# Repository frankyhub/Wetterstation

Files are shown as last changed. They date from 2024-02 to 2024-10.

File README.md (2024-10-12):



<div align="center">

|[:skull:ISSUE](https://github.com/frankyhub/Wetterstation/issues?q=is%3Aissue)|[:speech_balloon: Forum /Discussion](https://github.com/frankyhub/Wetterstation/discussions)|[:grey_question:WiKi](https://github.com/frankyhub/Wetterstation/wiki)||
|--|--|--|--|
| | | | |
||<a href="https://github.com/frankyhub/Wetterstation/issues">|<a href="https://github.com/frankyhub/Wetterstation/discussions">|<a href="https://github.com/frankyhub/Wetterstation/releases">|
|| <a href="https://github.com/frankyhub/Wetterstation/pulse" alt="Activity">| <a href="https://github.com/frankyhub/Wetterstation/graphs/traffic">  |<a href="https://github.com/frankyhub?tab=stars"> |
</div>

# Wetterstation
Wetterdaten, Raumklima, Datum und Uhrzeit

## Story:
Diese Anleitung beschreibt den Aufbau einer Wetterstation in einem Holzgehäuse mit einem ESP32. Beim ESP32 ist ein DHT11-Sensor und am I²C-Bus ein OLED 1,3"-Display angeschlossen. Die Wetterstation beinhaltet einen WiFi-Manager für die Einstellung der WLAN-Zugangsdaten (SSID und Passwort). Nach den ersten Start der Wetterstation, muss in den WLAN-Einstellungen des Handy oder Tablet das Netzwerk "Wetterstation" ausgewählt und über einen Browser die IP-Adresse 192.168.4.1 aufgerufen werden. Danach startet die "Wetterstation WLAN-Einstellung" und die Zugangsdaten für das WLAN können eingetragen werden. Sind die Zugangsdaten korrekt, startet die Wetterstation.
Die Wetterstation zeigt beim Start für 5 Sekunden einen Smiley. In dieser Zeit werden die aktuelle Uhrzeit, das Datum und die aktuellen Wetterdaten aus der Region Tegernsee von de.pool.ntp.org und von openweathermap.org geladen.
Sind die Daten geladen, verschwindet der Smiley und es werden in regelmäßigen Abständen drei Seiten mit Datum und Uhrzeit, danach das Raumklima mit Temperatur und Luftfeuchte, zuletzt die Wetterdaten Außen-Temperatur, Windgeschwindigkeit und Luftdruck angezeigt.

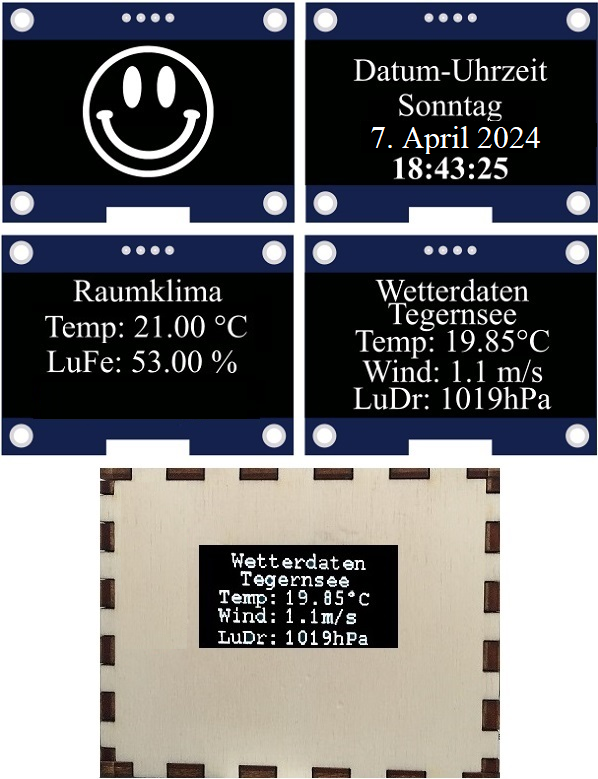
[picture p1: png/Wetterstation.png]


## Hardware:
Das benötigen wir für die Wetterstation:

| Anzahl | Bezeichnung | 
| --- | --- |
| 1 | ESP32 |
| 1 | ESP32-Shield | 
| 1 | ESP32 Stiftleiste | 
| 1 | DHT11-Sensor | 
| 1 | 10k Widerstand | 
| 1 | OLED Display 1,3" I²C | 
| 1 | OLED Display Anschluss 4 pol. |
| 1 | 8V Netzteil | 
| 1 | Sperrholzplatte 4mm x 600x300 | 
| 1 | 3D-Druck Teile für den ESP32, das OLED-Display und den DHT11 | 
| 1 | Schaltdraht | 
| 1 | Sekundenkleber | 
| 1 | Holzkleber |
| -------- | -------- | 

## Der Aufbau erfolgt in 5 Schritten:

1. Schritt Verdrahten

+ Wir löten auf das ESP32-Shield die Stiftleisten
+ Am ESP32-Shield wird ein 10kΩ Pullupwiderstand gegen +5V angelötet
+ Wir schließen mit Schaltdraht den DHT11-Sensor am ESP32-Shield GPIO27 an
+ Wir verdrahten den DHT11 mit +5V und GND
+ Wir verbinden mit Schaltdraht den I²C-Bus mit dem Display
+ Dazu werden die Lötpunkte SLA, SLC, 3.3V und GND mit dem Display verbunden
+ Ist der ESP32 auf dem Shield, der Sensor und das Display angelötet, erfolgt der erste Test
+ Wir laden einen I²C-Scanner in den ESP32 und kontrollieren ob der ESP32 die Busteilnehmer erkennt
+ Wird das Display erkannt, laden wir das Haupt-Programm in den ESP32

Stiftleisten einlöten:
  
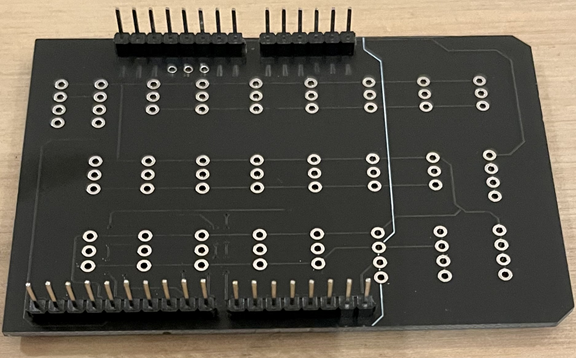
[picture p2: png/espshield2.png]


DHT11 anlöten:

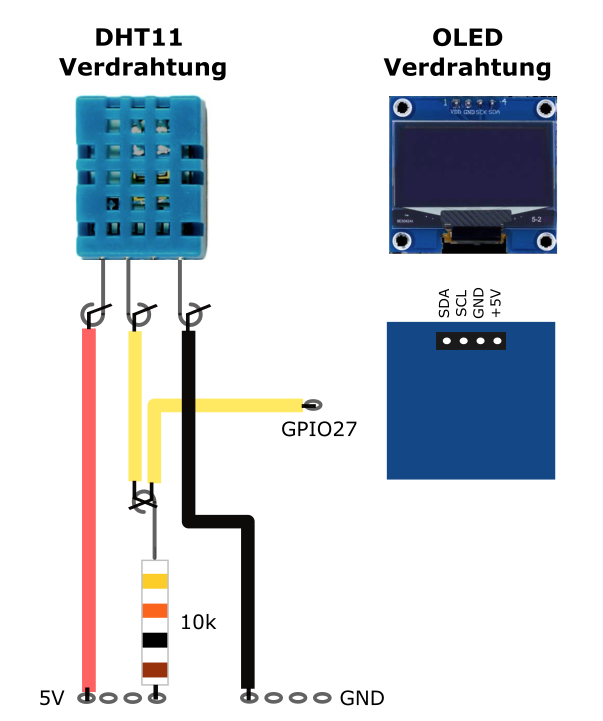
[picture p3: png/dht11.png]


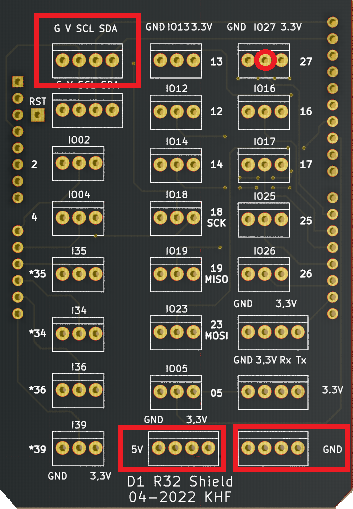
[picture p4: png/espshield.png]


Bild

---

2. Schritt 3D-Druckteile zeichnen und drucken

+ 3D-Druckteile zeichnen und drucken
+ 4 x ESP32-Pins d=5mm h=7mm
+ 4 x OLED-Display Pins 10x4x1,6mm
+ 1 x DHT11-Halterung 24x8x21 mit DHT11 Aussparung

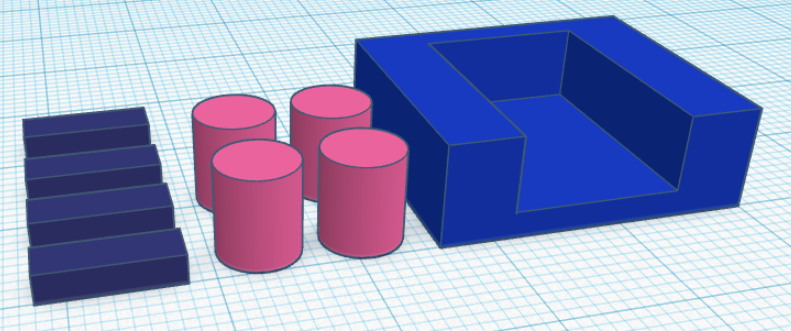
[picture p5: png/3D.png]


---

3. Schritt Gehäuse lasern

+ Wir erstellen mit [BOXES.PY](https://festi.info/boxes.py/) eine Lasercutter Vorlage
+ Wähle die ClosedBox - Fully closed box mit den Maßen x=110, y=90, h=90 und thickness=4
+ Zusätzlich werden runde Öffnungen für den DHT11-Sensor in der Frontseinte,
+ eine Aussparung für das OLED-Display und
+ zwei Aussparungen für den Spannungs- und Programmieranschluss des ESP32 in der Seitenwand eingefügt

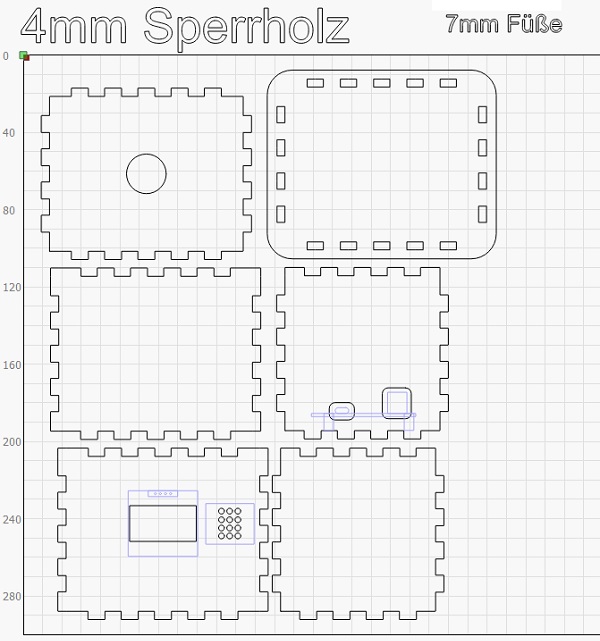
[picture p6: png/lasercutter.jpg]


---

4. Schritt Montage

+ Mit Sekundenkleber die 3D-Druck Bauteilfüße auf den ESP32 kleben
+ Die 3D-Druck Leisten auf das OLED-Display kleben
+ Die DHT11-Halterung an die Front-Innenseite kleben
+ VORSICHTIG das Display an die Front-Innenseite kleben
+ Den ESP32 zu den Aussparungen der Seitenwand justieren und auf die Grundplatte kleben
+ Vor dem finalen verkleben des Gehäuses erfolgt ein Funktionstest
+ War der Funktionstest erfolgreich, kann das Gehäuse vollständig verklebt werden

Bild  

Bild  

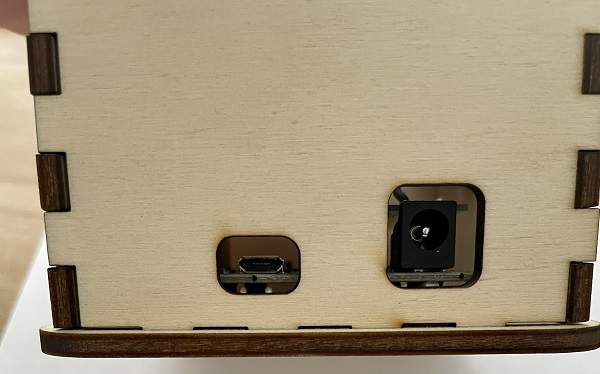
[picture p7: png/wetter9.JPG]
  

Erster Funktionstest am Seriellen Monitor:

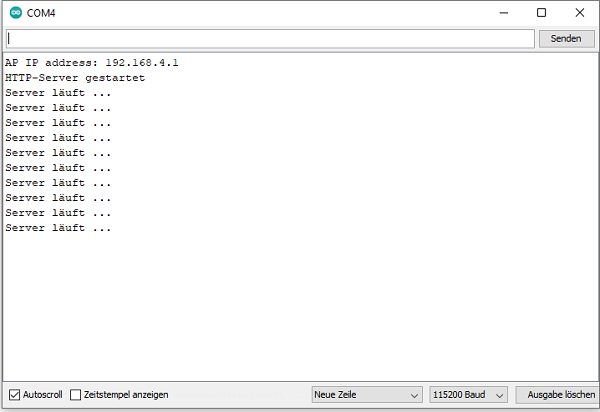
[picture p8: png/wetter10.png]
  

---

5. Schritt Inbetriebnahme

+ Im Handy oder Tablet die WLAN-Einstellungen öffnen
+ Das Netzwerk "Wetterstation" aufrufen
+ Im Browser die IP-Adresse 192.168.4.1 aufrufen
+ Die Seite "Wetterstation WLAN Einstellung" öffnet sich
+ Die WLAN-Zugangsdaten SSID und Passwort eingeben und speichern
+ Der Zeitserver ist voreingestellt und muss nicht verändert werden
+ Ist die WLAN-Verbindung korrekt, startet die Wetterstation mit einem Smiley am Display
+ Danach werden abwechselnd das aktuelle Datum mit Uhrzeit, danach das Raumklima mit Temperatur und Luftfeuchte und die aktuellen Wetterdaten aus der Region Tegernsee angezeigt
+ Die angezeigten Daten wechseln in regelmäßigen Abständen

Aufruf "Wetterstation" in den WLAN-Einstellungen

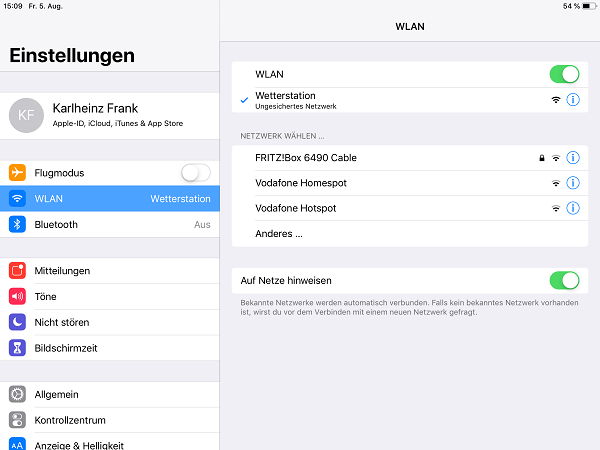
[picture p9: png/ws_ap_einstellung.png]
  

Im Browser die IP-Adresse 192.168.4.1 öffnen, die WLAN Zugangsdaten eingeben und speichern

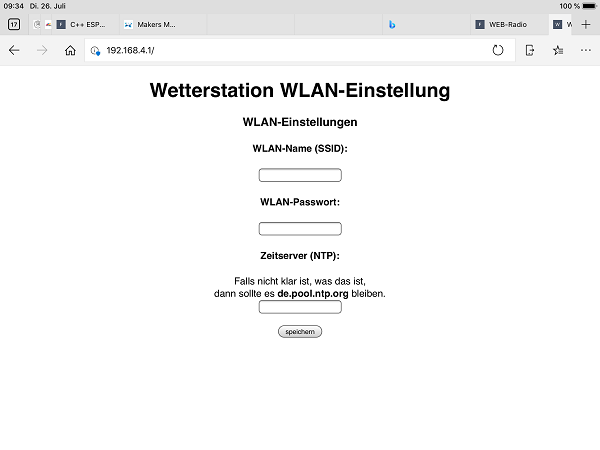
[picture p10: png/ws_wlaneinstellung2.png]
  

Sind die WLAN-Zugangsdaten korrekt, startet die Wetterstation

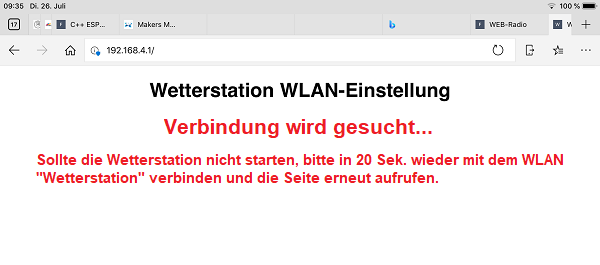
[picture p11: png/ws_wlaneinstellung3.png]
  

Startet die Wetterstation nicht, muss der Vorgang wiederholt werden.
Kontrolle am Seriellen Monitor:

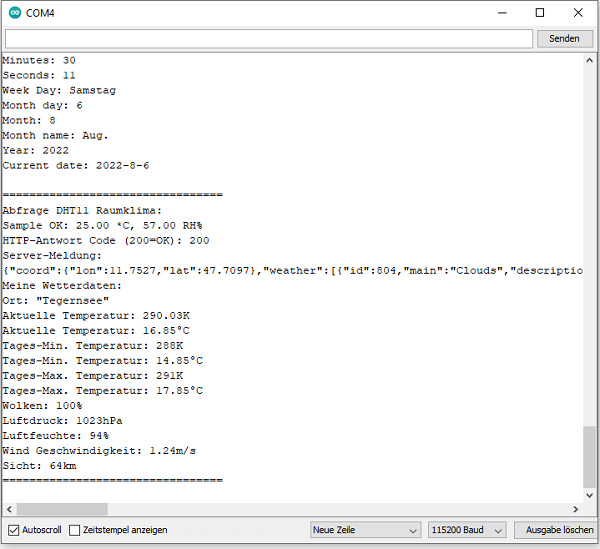
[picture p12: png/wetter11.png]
  

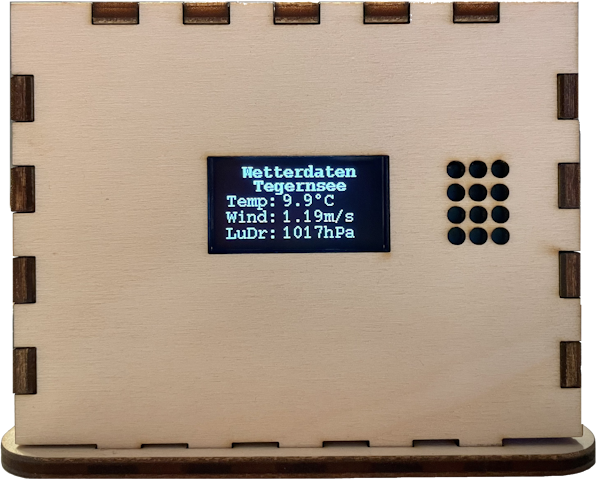
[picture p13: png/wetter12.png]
  

Fertig, Glückwunsch!

---

## Troubleshooting, mögliche Fehlerursachen

+ Sichtkontrolle - sind alle Lötstellen ok?
+ Sind Lötbrücken zusehen oder sind Bauteilfüße fälschlicherweise mit einander verbunden?
+ Sitzt der ESP32 korrekt auf dem Shield? Auf die Polung achten und und Bauteilfüße kontrollieren.
+ Sind die Anschlussdrähte zum Sensor und Display ok?
+ Ist die Spannungsversorgung für den ESP32 ok?
+ Wurde das Programm korrekt geladen? Meldung: Hochladen abgeschlossen.
+ Wird das Display vom ESP32 erkannt? Mit dem I²C-Scanner prüfen.
+ Werden die Sensordaten und die Uhrzeit/Datum ausgelesen? Mit dem Seriellen Montitor der Arduino IDE prüfen.
+ Wurden die WLAN-Zugangsdaten korrekt eingegeben?

---

## Abkürzungen

+ OLED - Organic Light Emitting Diode
+ u8g2 Library - Universal 8Bit Graphics Library
+ I²C - Inter-Integrated Circuit (Serieller Datenbus)
+ SCL - Serial Clock
+ SDA - Serial Data

---

## C++ Programm I2C Scanner

```C++
// ESP32 I2C Scanner 
// ESP32 DevKit / ESP32vn IoT UNO - Arduino IDE 1.8.
#include <Wire.h>
void setup()
{
  Serial.begin (115200);  
  Wire.begin (21, 22);   // sda= GPIO_21 /scl= GPIO_22
}
void Scanner ()
{
  Serial.println ();
  Serial.println ("I2C scanner. Scanning ...");
  byte count = 0;
  Wire.begin();
  for (byte i = 8; i < 120; i++)
  {
    Wire.beginTransmission (i);          // Begin I2C transmission Address (i)
    if (Wire.endTransmission () == 0)  // Receive 0 = success (ACK response) 
    {
      Serial.print ("Found address: ");
      Serial.print (i, DEC);
      Serial.print (" (0x");
      Serial.print (i, HEX);     // PCF8574 7 bit address
      Serial.println (")");
      count++;
    }
  }
  Serial.print ("Found ");      
  Serial.print (count, DEC);        // numbers of devices
  Serial.println (" device(s).");
}
void loop()
{
  Scanner ();
  delay (100);
}
```

---

<div style="position:absolute; left:2cm; ">   
<ol class="breadcrumb" style="border-top: 2px solid black;border-bottom:2px solid black; height: 45px; width: 900px;"> <p align="center"><a href="#oben">nach oben</a></p></ol>
</div>  

---

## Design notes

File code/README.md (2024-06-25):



# Wetterstation mit Gassensor MQ135

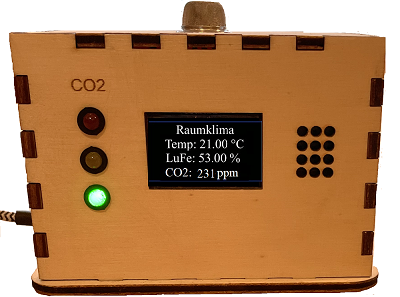
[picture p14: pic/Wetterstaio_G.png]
Bild


## Story:
Ziel der Erweiterung um einen Gassensor ist es, die CO2-Konzentration in Teilen pro Million zu messen, sie auf 
einem Bildschirm anzuzeigen und uns eine akustische Warnung zu geben, wenn sie eine gefährliche 
Konzentration erreicht. Die Anzeige erfolgt auch über drei verschiedenfarbige 
LEDs, die schnell eine visuelle Information über die Höhe der CO2-Konzentration geben. 

Der MQ-135-Sensor misst die CO2-Konzentration in Teilen pro Million. Die Daten 
werden auch im zweifarbigen OLED-Bildschirm mit 1,3 Zoll gesendet, um jeden Wert in 
Intervallen anzuzeigen. Die grüne LED leuchtet, wenn die Konzentration 
gleich oder kleiner als 550 ist. Die gelbe LED leuchtet, wenn die Konzentration zwischen 551 und 799 
Teilen pro Million CO2 liegt und die rote LED leuchtet zusammen mit einem Summerton, wenn die Konzentration 
799 Teile pro Million übersteigt. Diese drei Werte können auch konfiguriert werden.
Es ist sehr wichtig, den Sensor unabhängig mit 5 VDC zu versorgen, da er 850 mW verbraucht.

## Kalibrierung:
Als erstes muss der MQ-135-Sensor vorbereitet werden, damit er die richtigen Werte misst, die wir im 
nächsten Schritt verwenden werden. Dazu muss der Sensor im Neuzustand etwa 2 Stunden lang mit 5 Volt 
betrieben werden, damit die bei der Herstellung entstandenen Verunreinigungen beseitigt werden. 
Danach ist es am besten, den Referenzabgleich des RZERO-Widerstands in der endgültigen Schaltung 
vorzunehmen, da dies mit den normalerweise verwendeten Versorgungs- und Betriebsspannungen geschieht 
und die Messung optimal ist.
Ziel dieser Kalibrierung ist es, den Widerstand des atmosphärischen CO2-Niveaus so einzustellen, 
dass der MQ-135-Sensor eine Konzentration zwischen 300 und 450 ppm misst, was der normalen Konzentration 
dieses Gases in der Umwelt entspricht. 

Wenn alles angeschlossen ist, starten wir die Arduino-IDE, laden und starten den Sketch "MQ135_Kalibrieren.ino". 
Zuvor muss die MQ135-Bibliothek installiert werden. Wir öffnen den seriellen Monitor und sehen den ppm-Messwert; 
wir müssen den RZERO-Wert in der Datei MQ135.h im Bibliotheksordner der Arduino IDE ändern und speichern, bis der 
ppm-Messwert derjenige ist, den wir als Arbeitsreferenz der Schaltung belassen wollen. Der zu ändernde Wert ist 
der grün gefärbte Wert.

Um die Einstellung vorzunehmen, müssen wir den Wert von RZERO ändern, die Änderungen der Datei MQ135.h 
der Bibliothek in ihrem Ordner der Arduino IDE speichern und den Kalibrierungs-Sketch neu laden, den 
neuen Wert der CO2-Konzentration im seriellen Monitor überprüfen und den Vorgang wiederholen, um RZERO 
mit dem Wert einzustellen, den wir als Referenz für die CO2-Konzentration in der Luft für die Warngrenzen im 
Sketch unseres Projekts lassen wollen.

<div style="position:absolute; left:2cm; ">   
<ol class="breadcrumb" style="border-top: 2px solid black;border-bottom:2px solid black; height: 45px; width: 900px;"> <p align="center"><a href="#oben">nach oben</a></p></ol>
</div>

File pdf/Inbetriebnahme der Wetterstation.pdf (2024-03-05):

Inbetriebnahme der Wetterstation

Die Wetterstation zeigt die Uhrzeit, Datum und die aktuellen Wetterdaten in einem OLED-Display an und aktualisiert alles in regelmäßigen Abständen, Damit das funktioniert benötigt die Wetterstation einen WLAN-Zugang.

Die Wetterstation beinhaltet einen WiFi-Manager für die Einstellung der WLAN-Zugangsdaten (SSID und Passwort). Nach dem ersten Start der Wetterstation, muss in den WLAN-Einstellungen des Handys, PC oder Tablet das Netzwerk "Wetterstation" ausgewählt und über einen Browser die IP-Adresse 192.168.4.1 aufgerufen werden.

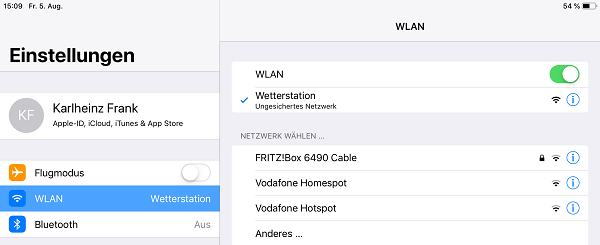
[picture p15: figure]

Danach startet die "Wetterstation WLAN-Einstellung" und die Zugangsdaten für das WLAN können eingetragen werden.

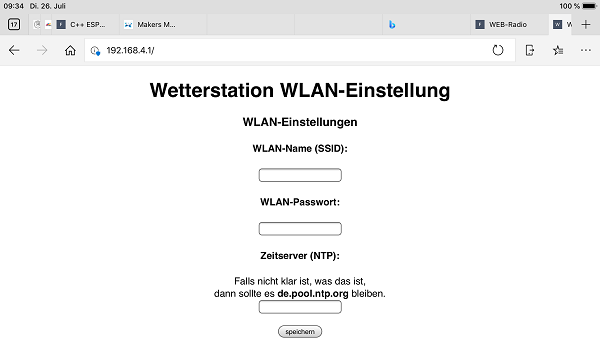
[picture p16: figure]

Sind die Zugangsdaten korrekt, startet die Wetterstation.
Die Wetterstation zeigt beim Start für 5 Sekunden einen Smiley. In dieser Zeit werden die aktuelle Uhrzeit, das Datum und die aktuellen Wetterdaten aus der Region von de.pool.ntp.org und von openweathermap.org geladen.
Sind die Daten geladen, verschwindet der Smiley und es werden in regelmäßigen Abständen drei Seiten mit Datum und Uhrzeit, danach das Raumklima mit Temperatur und Luftfeuchte, zuletzt die Wetterdaten Außen-Temperatur, Windgeschwindigkeit und Luftdruck angezeigt.

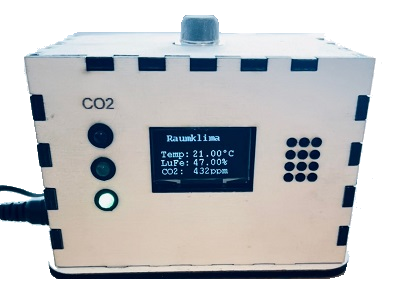
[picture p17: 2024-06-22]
pic/Wettertstation.png

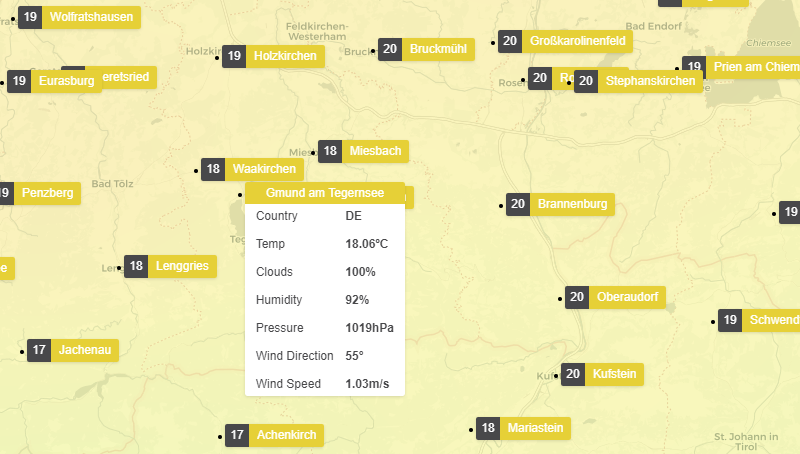
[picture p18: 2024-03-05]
png/13wetter.png

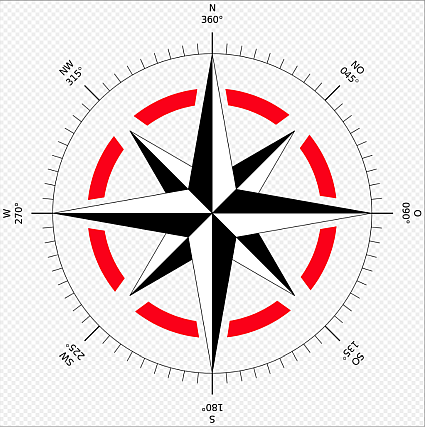
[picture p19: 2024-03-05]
png/14wetter.png

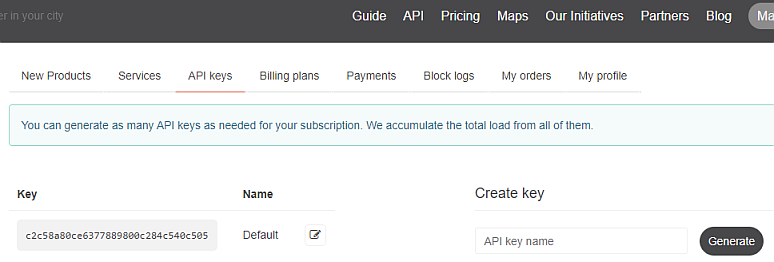
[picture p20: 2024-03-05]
png/11wetter.png

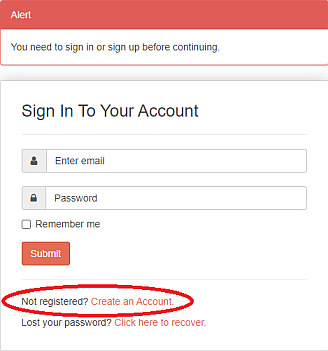
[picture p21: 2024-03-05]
png/10wetter.png

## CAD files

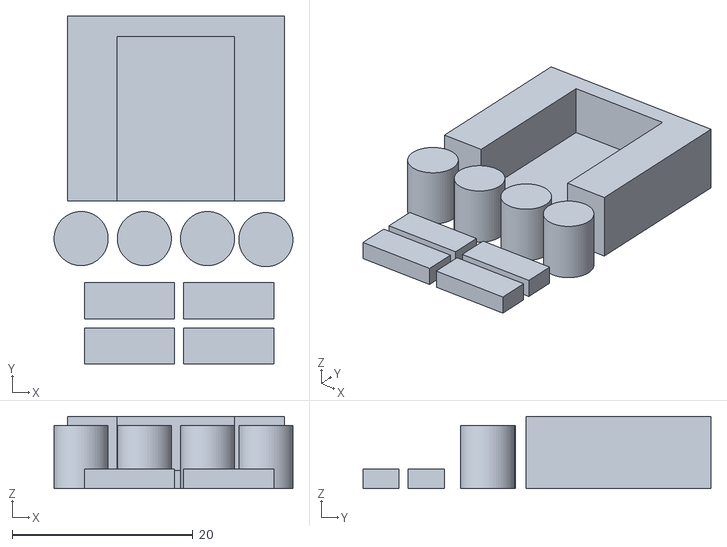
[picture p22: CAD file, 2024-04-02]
3D/Wetterstation.stl
26.5 x 38.5 x 8.00

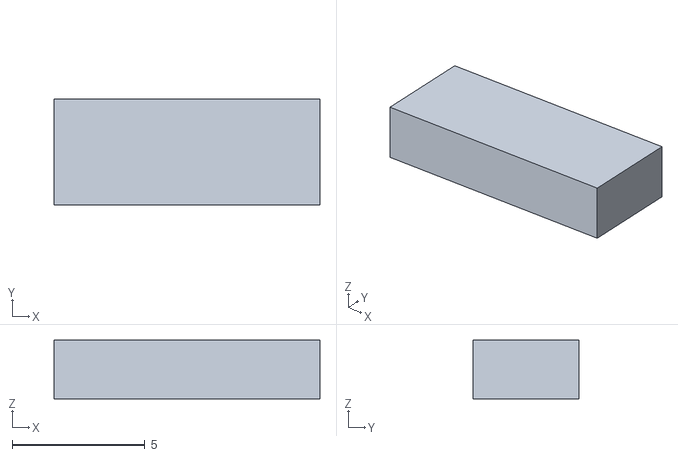
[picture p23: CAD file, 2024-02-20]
3D/OLED-Spacer.stl
10.0 x 4.00 x 2.20

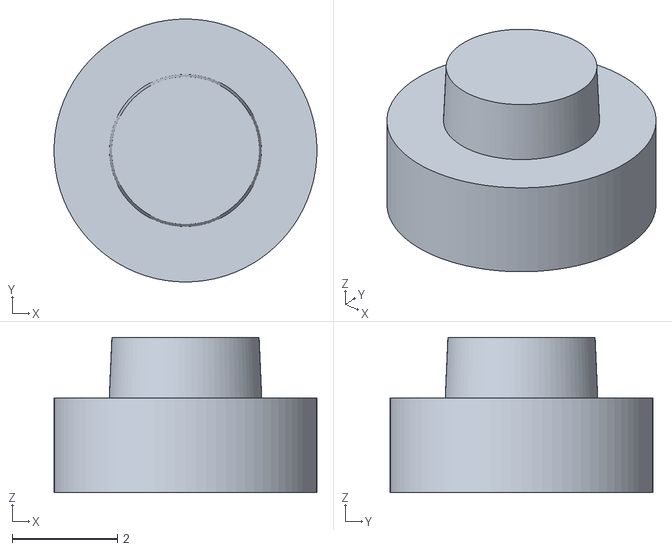
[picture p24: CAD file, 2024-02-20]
3D/Display-PIN.stl
5.00 x 5.00 x 2.95

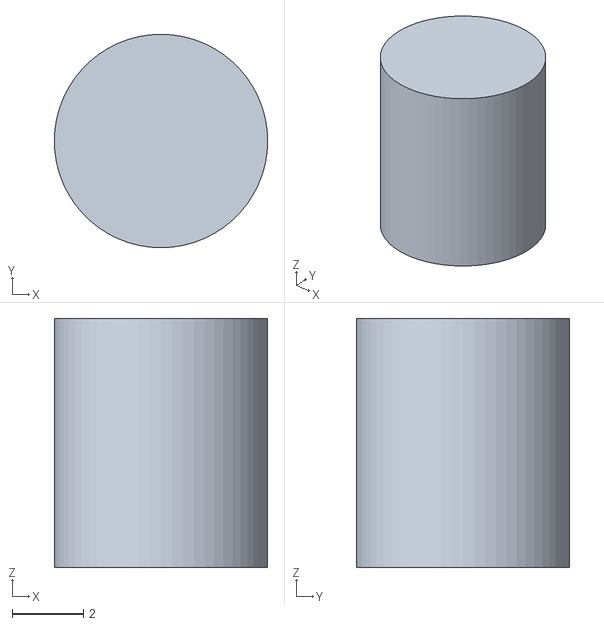
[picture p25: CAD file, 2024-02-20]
3D/ESP32_PIN_7mm.stl
6.00 x 6.00 x 7.00

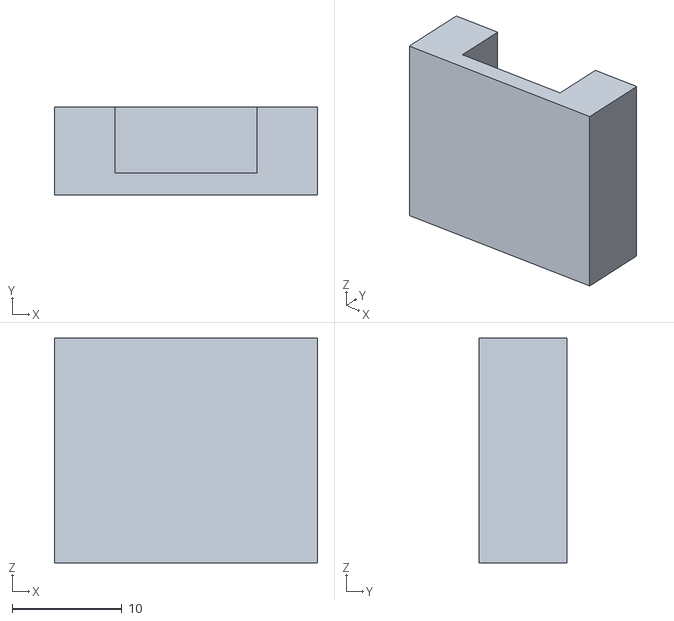
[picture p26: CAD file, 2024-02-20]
3D/DHT11-Halter.stl
24.0 x 8.00 x 20.5

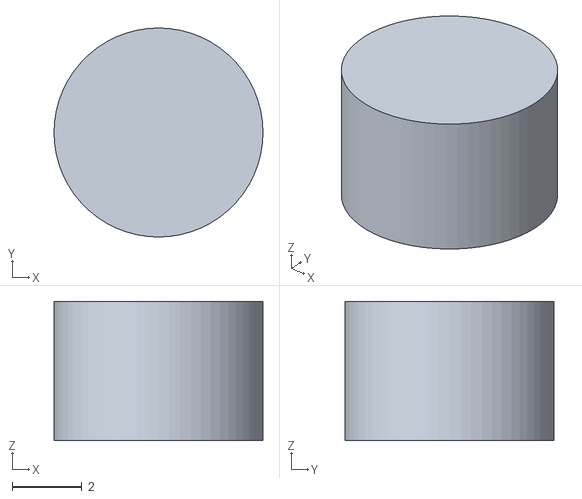
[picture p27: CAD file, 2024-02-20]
3D/ESP Spacer.stl
6.00 x 6.00 x 4.00

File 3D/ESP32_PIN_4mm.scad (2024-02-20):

//Platinen Pin ESP32 UNO Wetterstation
//4x

$fn=60;
Rgr = 3; //Radius PIN 
R1kl = 0; //Radius 1 Stift
R2kl = 0; //Radius 2 Stift
Sh = 4;       //Sockelhöhe


cylinder(h = Sh, r1=Rgr , r2=Rgr , center = true);
translate(v = [0, 0, Sh/2])
cylinder(h = 3, r1 = R1kl, r2 = R2kl, center = true);

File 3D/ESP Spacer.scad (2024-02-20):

//ESP Spacer

$fn=60;
color("WhiteSmoke")
cylinder(h = 4, r1 = 3, r2 = 3, center = true); 

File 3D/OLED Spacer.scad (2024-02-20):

//OLED Spacer

$fn=60;

cube(size = [10,4,2.2], center = true);

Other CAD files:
3D/ESP32_PIN_4mm.stl
3D/Display-PIN.scad
3D/DHT11-Halter.scad
3D/ESP32_PIN_7mm.scad

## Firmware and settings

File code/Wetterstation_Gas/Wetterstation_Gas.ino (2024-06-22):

/*************************************************************************************************
                                      PROGRAMMINFO
**************************************************************************************************
  Funktion: ESP32 Wetterstation mit WLAN-Manager - Wetterdaten Tegernsee und Raumklima DHT11 OLED1,3"
            Gas-Sensor MQ135, Buzzer und Gas LED-Ampel
**************************************************************************************************
  Version: 22.06.2024
**************************************************************************************************
  Board: ESP32vn IoT UNO V1.0.4 /1.0.6

**************************************************************************************************
  C++ Arduino IDE V1.8.19
**************************************************************************************************
  Einstellungen:
  https://dl.espressif.com/dl/package_esp32_index.json
  http://dan.drown.org/stm32duino/package_STM32duino_index.json
  https://raw.githubusercontent.com/espressif/arduino-esp32/gh-pages/package_esp32_dev_index.json
**************************************************************************************************

  Server-Abfrage:
  http://api.openweathermap.org/data/2.5/weather?q=Tegernsee,DE&APPID=c2c58a80ce6377889800c284c540c505

  JSON-Meldung:
  {"coord":{"lon":11.7527,"lat":47.7097},
  "weather":
  [{"id":804,"main":"Clouds","description":"overcast clouds","icon":"04d"}],

  "base":"stations",
  "main":
  {"temp":288.35,
  "feels_like":288.54,
  "temp_min":285.19,
  "temp_max":291.7,
  "pressure":1016,
  "humidity":100,
  "sea_level":1016,
  "grnd_level":932},
  "visibility":273,
  "wind":{"speed":1.75,"deg":30,"gust":3.01},

  "clouds":{"all":100},
  "dt":1625628595,
  "sys":{"type":2,"id":2001431,"country":"DE","sunrise":1625628176,"sunset":1625685150},
  "timezone":7200,"id":2823679,"name":"Tegernsee","cod":200

  Beispiele für Schriftarten:
  Schrift­hö­he in Pixeln (px)
  6px: u8g2_font_5x7_tr
  7px: u8g2_font_torussansbold8_8r
  8px: u8g2_font_ncenB08_tr
  10px: u8g2_font_t0_15b_me
  12px: u8g2_font_helvB12_tf
  13px: u8g2_font_t0_22_te
  14px: u8g2_font_helvB14_tf
  17px: u8g2_font_timB18_tf
  18px: u8g2_font_lubB18_tr
  20px: u8g2_font_courB24_tf
  23px: u8g2_font_timB24_tf
  25px: u8g2_font_helvR24_tf
  32px: u8g2_font_logisoso32_tf
  42px: u8g2_font_fub42_tf
  58px: u8g2_font_logisoso58_tf
  62px: u8g2_font_logisoso62_tn

 **************************************************************************************************/

#include <SimpleDHT.h> //by Winlin 1.0.14       
int pinDHT11 = 27;
SimpleDHT11 dht11(pinDHT11);
#include <Adafruit_Sensor.h> //by Adafruit 0.8.0
#include <WiFi.h> //by Arduino 1.2.7
#include <WiFiUdp.h> 
#include <NTPClient.h> //Easy NTPC ba Harshen Alva 1.1.0
#include <HTTPClient.h> //Arduino HTTPClient by Arduino 0.4.0
#include <Arduino_JSON.h> //by Arduino 0.1.0

//------- Gas Sensor MQ135 ------------
int Buzzer = 26;        
int Gas_analog = 39;  
int Gas_digital = 2;   

#define led_rot 25
#define led_gelb 17
#define led_gruen 16
//----------------------------------------


String openWeatherMapApiKey = "c2c58a80ce6377889800c284c540c505";
String city = "Tegernsee";
String countryCode = "DE";

unsigned long lastTime = 0;
unsigned long timerDelay = 10000; //10 Sekunden
String jsonBuffer;

//-----------------------------------------------
#include <Arduino.h>
#include <U8g2lib.h>


#ifdef U8X8_HAVE_HW_SPI
#include <SPI.h>
#endif
#ifdef U8X8_HAVE_HW_I2C
#include <Wire.h>
#endif

U8G2_SH1106_128X64_NONAME_F_HW_I2C u8g2(U8G2_R0, /* reset=*/ U8X8_PIN_NONE);
unsigned long delayTime;
//-----------------------------------------------
int ktemp;
int mintemp;
int maxtemp;
int sicht;

//----------------clock----------------------------
// Define NTP Client to get time

WiFiUDP ntpUDP;
NTPClient timeClient(ntpUDP, "de.pool.ntp.org");


 // Internetzeit
#define MY_NTP_SERVER "de.pool.ntp.org"
#define MY_TZ "CET-1CEST,M3.5.0/02,M10.5.0/03" // https://github.com/nayarsystems/posix_tz_db/blob/master/zones.csv
time_t now;
tm tm;
void showTime() {
  time(&now);
  localtime_r(&now, &tm); // update the structure tm with the current time
   Serial.print("Jahr:");
    Serial.print(tm.tm_year + 1900); // years since 1900
    Serial.print("\tmonth:");
    Serial.print(tm.tm_mon + 1); // January = 0 (!)
    Serial.print("\tday:");
    Serial.print(tm.tm_mday); // day of month
    Serial.print("\thour:");
    Serial.print(tm.tm_hour); // hours since midnight 0-23
    Serial.print("\tmin:");
    Serial.print(tm.tm_min); // minutes after the hour 0-59
    Serial.print("\tsec:");
    Serial.print(tm.tm_sec); // seconds after the minute 0-61*
    Serial.print("\twday");
    Serial.print(tm.tm_wday); // days since Sunday 0-6
  
  Serial.println();
}


//Week Days
String weekDays[7] = {"Sonntag", "Montag", "Dienstag", "Mittwoch", "Donnerstag", "Freitag", "Samstag"};

//Month names
  String months[12] = {"Jan", "Feb", "M""\xE4""rz", "Apr", "Mai", "Juni", "Juli", "Aug", "Sept", "Okt", "Nov", "Dez"};
//-----------------------------------------------

void setup() {
  Serial.begin(115200);
   //init WiFi
  Serial.println("Connecting to WiFi");
  while (!makeWLAN()) {
    Serial.println("Cannot connect :(");
    delay(1000);
  }

//------- Gas Sensor MQ135 ------------
    pinMode(Buzzer, OUTPUT);      
    pinMode(Gas_digital, INPUT);
    pinMode(led_rot, OUTPUT);
    pinMode(led_gruen, OUTPUT);
    pinMode(led_gelb, OUTPUT);
//----------------------------------------  

  Serial.println("Aktualisierung ist auf 10 Sekunden eingestellt.");

  // Initialize a NTPClient to get time
  timeClient.begin();
  // Set offset time in seconds to adjust for your timezone, for example:
  // GMT +1 = 3600 Winterzeit
  // GMT +2 = 7200 Sommerzeit
  timeClient.setTimeOffset(7200);

  u8g2.begin();

  int BildschirmBreite = u8g2.getDisplayWidth();
  int BildschirmHoehe = u8g2.getDisplayHeight();



//Bitmap hier einfügen:
//Smiley XBM erstellt mit GIMP
//Smiley 50x50
#define smiley_width 50
#define smiley_height 50
static unsigned char smiley[] = {
   0x00, 0x00, 0x00, 0x00, 0x00, 0x00, 0x00, 0x00, 0x00, 0x00, 0x02, 0x00,
   0x00, 0x00, 0x00, 0x00, 0xfc, 0x7f, 0x00, 0x00, 0x00, 0x00, 0x00, 0xff,
   0xff, 0x03, 0x00, 0x00, 0x00, 0xc0, 0x07, 0xc0, 0x0f, 0x00, 0x00, 0x00,
   0xf0, 0x00, 0x00, 0x3e, 0x00, 0x00, 0x00, 0x3c, 0x00, 0x00, 0x78, 0x00,
   0x00, 0x00, 0x1c, 0x00, 0x00, 0xe0, 0x00, 0x00, 0x00, 0x07, 0x00, 0x00,
   0xc0, 0x01, 0x00, 0x80, 0x07, 0x00, 0x00, 0x80, 0x03, 0x00, 0x80, 0x01,
   0x08, 0xc0, 0x00, 0x07, 0x00, 0xc0, 0x01, 0x1c, 0xc0, 0x00, 0x0e, 0x00,
   0xe0, 0x00, 0x1c, 0xe0, 0x01, 0x0c, 0x00, 0x60, 0x00, 0x1e, 0xe0, 0x01,
   0x18, 0x00, 0x30, 0x00, 0x1e, 0xe0, 0x01, 0x38, 0x00, 0x30, 0x00, 0x3e,
   0xe0, 0x01, 0x30, 0x00, 0x18, 0x00, 0x1e, 0xe0, 0x01, 0x70, 0x00, 0x18,
   0x00, 0x1e, 0xe0, 0x01, 0x60, 0x00, 0x1c, 0x00, 0x1e, 0xe0, 0x01, 0x60,
   0x00, 0x0c, 0x00, 0x1c, 0xe0, 0x01, 0x60, 0x00, 0x0c, 0x00, 0x1c, 0xc0,
   0x01, 0xc0, 0x00, 0x0c, 0x00, 0x1c, 0xc0, 0x00, 0xc0, 0x00, 0x0c, 0x00,
   0x00, 0x80, 0x00, 0xc0, 0x00, 0x0c, 0x00, 0x00, 0x00, 0x00, 0xc0, 0x00,
   0x06, 0x00, 0x00, 0x00, 0x00, 0xc0, 0x00, 0x0e, 0x04, 0x00, 0x00, 0x80,
   0xc1, 0x00, 0x0c, 0x03, 0x00, 0x00, 0x00, 0xc1, 0x00, 0x0c, 0x04, 0x00,
   0x00, 0x80, 0xc0, 0x00, 0x0c, 0x04, 0x00, 0x00, 0x00, 0xc0, 0x00, 0x0c,
   0x04, 0x00, 0x00, 0x80, 0xc0, 0x00, 0x0c, 0x00, 0x00, 0x00, 0x80, 0xe0,
   0x00, 0x1c, 0x08, 0x00, 0x00, 0x40, 0x60, 0x00, 0x18, 0x08, 0x00, 0x00,
   0x40, 0x60, 0x00, 0x18, 0x10, 0x00, 0x00, 0x20, 0x70, 0x00, 0x38, 0x20,
   0x00, 0x00, 0x10, 0x30, 0x00, 0x30, 0x40, 0x00, 0x00, 0x10, 0x38, 0x00,
   0x70, 0x80, 0x00, 0x00, 0x04, 0x18, 0x00, 0x60, 0x00, 0x01, 0x00, 0x02,
   0x1c, 0x00, 0xe0, 0x00, 0x06, 0x80, 0x01, 0x0c, 0x00, 0xc0, 0x01, 0x70,
   0x30, 0x00, 0x07, 0x00, 0x80, 0x03, 0x80, 0x05, 0x00, 0x07, 0x00, 0x00,
   0x07, 0x00, 0x00, 0x80, 0x03, 0x00, 0x00, 0x0e, 0x00, 0x00, 0xe0, 0x01,
   0x00, 0x00, 0x3c, 0x00, 0x00, 0x70, 0x00, 0x00, 0x00, 0xf8, 0x00, 0x00,
   0x3c, 0x00, 0x00, 0x00, 0xe0, 0x03, 0x00, 0x1f, 0x00, 0x00, 0x00, 0x80,
   0xbf, 0xf4, 0x07, 0x00, 0x00, 0x00, 0x00, 0xfe, 0xff, 0x01, 0x00, 0x00,
   0x00, 0x00, 0xd0, 0x2f, 0x00, 0x00, 0x00, 0x00, 0x00, 0x00, 0x00, 0x00,
   0x00, 0x00 };
   
  u8g2.setFont(u8g2_font_courR10_tf);
  u8g2.firstPage();

  do {
    u8g2.clearBuffer();
    u8g2.drawXBM(40, 0, smiley_width, smiley_height, smiley);
        u8g2.setCursor(12, 62);
        u8g2.setFont(u8g2_font_courB08_tf);
        u8g2.print("Ich lade die Daten");
   } while ( u8g2.nextPage() );
  delay(3000);
  
}//Ende Setup

  
void loop() {


  //----------------Clock----------------------
  timeClient.update();
  time_t epochTime = timeClient.getEpochTime();
  showTime();
  //  Serial.print("Epoch Time: ");
  //  Serial.println(epochTime);

  String formattedTime = timeClient.getFormattedTime();
  // Serial.print("Formatted Time: ");
  // Serial.println(formattedTime);

  int currentHour = timeClient.getHours();
  char stunden = timeClient.getHours();


  //  Serial.print("Hour: ");
  //  Serial.println(currentHour);

  int currentMinute = timeClient.getMinutes();
  //  Serial.print("Minutes: ");
  //  Serial.println(currentMinute);

  int currentSecond = timeClient.getSeconds();
  //  Serial.print("Seconds: ");
  //  Serial.println(currentSecond);

  String weekDay = weekDays[timeClient.getDay()];
  char tag = timeClient.getDay();
   Serial.println("**************** Datum und Uhrzeit ********************");
   Serial.println(tag);

    Serial.print("Wochentag: ");
    Serial.println(weekDay);

  //Get a time structure
  struct tm *ptm = gmtime ((time_t *)&epochTime);

  int monthDay = ptm->tm_mday;
    Serial.print("Tag: ");
    Serial.println(monthDay);

  int currentMonth = ptm->tm_mon + 1;
   Serial.print("Monat: ");
   Serial.println(currentMonth);

  String currentMonthName = months[currentMonth - 1];
    Serial.print("Monat: ");
    Serial.println(currentMonthName);

  int currentYear = ptm->tm_year + 1900;
    Serial.print("Jahr: ");
    Serial.println(currentYear);

  //Print complete date:
  String currentDate = String(currentYear) + "-" + String(currentMonth) + "-" + String(monthDay);
    Serial.print("Datum: ");
    Serial.println(currentDate);

    Serial.println("");

  //---------------------------------------------------------

  Serial.println("=================================");
  Serial.println("Abfrage DHT11 Raumklima:");
  float temperature = 0;
  float humidity = 0;
  int err = SimpleDHTErrSuccess;
  if ((err = dht11.read2(&temperature, &humidity, NULL)) != SimpleDHTErrSuccess) {
    Serial.print("Read DHT11 failed, err=");
    Serial.println(err);
    delay(2000);
    return;
  }

  Serial.print("Sample OK: ");
  Serial.print((float)temperature);
  Serial.print(" *C, ");
  Serial.print((float)humidity);
  Serial.println(" RH%");
  delay(5000); // DHT11 Abfragezeit

  if ((millis() - lastTime) > timerDelay) {
    // Check WiFi Status
    if (WiFi.status() == WL_CONNECTED) {
      String serverPath = "http://api.openweathermap.org/data/2.5/weather?q=" + city + "," + countryCode + "&APPID=" + openWeatherMapApiKey;

      jsonBuffer = httpGETRequest(serverPath.c_str());
      Serial.println(jsonBuffer);
      JSONVar myObject = JSON.parse(jsonBuffer);

      if (JSON.typeof(myObject) == "undefined") {
        Serial.println("Eingabe fehlgeschlagen!");
        return;
      }
      ktemp = (myObject["main"]["temp"]);
      mintemp = (myObject["main"]["temp_min"]);
      maxtemp = (myObject["main"]["temp_max"]);

      //      Serial.print("JSON object = ");
      Serial.println("Meine Wetterdaten:");
      Serial.print("Ort: ");
      Serial.println(myObject["name"]);
      Serial.print("Aktuelle Temperatur: ");
      Serial.print(myObject["main"]["temp"]);
      Serial.println("K ");
      Serial.print("Aktuelle Temperatur: ");
      Serial.print(ktemp - 273.15);
      Serial.println("°C ");
      Serial.print("Tages-Min. Temperatur: ");
      Serial.print(mintemp);
      Serial.println("K ");

      Serial.print("Tages-Min. Temperatur: ");
      Serial.print(mintemp - 273.15);
      Serial.println("°C ");

      Serial.print("Tages-Max. Temperatur: ");
      Serial.print(maxtemp);
      Serial.println("K ");

      Serial.print("Tages-Max. Temperatur: ");
      Serial.print(maxtemp - 273.15);
      Serial.println("°C ");

      Serial.print("Wolken: ");
      Serial.print(myObject["clouds"]["all"]);
      Serial.println("% ");

      Serial.print("Luftdruck: ");
      Serial.print(myObject["main"]["pressure"]);
      Serial.println("hPa");
      Serial.print("Luftfeuchte: ");
      Serial.print(myObject["main"]["humidity"]);
      Serial.println("% ");
      Serial.print("Wind Geschwindigkeit: ");
      Serial.print(myObject["wind"]["speed"]);
      Serial.println("m/s ");

      sicht = (myObject["visibility"]);
      sicht = sicht / 100;
      Serial.print("Sicht: ");
      Serial.print(sicht);
      Serial.println("km ");

      //---------------------------------------------------------


//------- Gas Sensor MQ135 ------------
    int gassensorAnalog = analogRead(Gas_analog);
    int gassensorDigital = digitalRead(Gas_digital);
  delay(100);

  
  Serial.print("Gas Sensor: ");
  Serial.print(gassensorAnalog);
  Serial.print("\t");
  Serial.print(gassensorDigital);
  Serial.print("\t");
  Serial.print("\t");

  if (gassensorAnalog <= 300)  {
    Serial.println("kein Gas"); 
    digitalWrite(led_gruen, HIGH);        // OK   
  } else { 
    digitalWrite(led_gruen, LOW); }      

 
  if (gassensorAnalog >= 551 && gassensorAnalog <= 799) {
    digitalWrite(led_gelb, HIGH); 
        Serial.println("Gas erkannt");    
  } else {
    digitalWrite(led_gelb, LOW); }    
   

  
  if (gassensorAnalog > 800) { 
    Serial.println("Gas-Alarm");
    digitalWrite(led_rot, HIGH);         // Gas-Alarm
    digitalWrite (Buzzer, HIGH) ; //send tone

    } else {
    digitalWrite(led_rot, LOW);
    digitalWrite (Buzzer, LOW) ;  //no tone
    }
  delay(100);
//-----------------------------------------------------



      Serial.println("=================================");

      u8g2.setFont(u8g2_font_courR10_tf);
      u8g2.firstPage();


      do {
        u8g2.clearBuffer();
        u8g2.setCursor(6, 10);
        u8g2.print("Datum-Uhrzeit");
        u8g2.setFont(u8g2_font_courR10_tf);
        u8g2.setCursor(30, 27);
        u8g2.print(weekDay);
        u8g2.setCursor(3, 43);
        u8g2.print(monthDay);
        u8g2.print(". ");
        u8g2.print(currentMonthName);
        u8g2.print(" ");
        u8g2.print(currentYear);
        u8g2.setFont(u8g2_font_courB14_tf);
        u8g2.setCursor(40, 63);

        u8g2.print(currentHour);
        u8g2.print(":");
         if (currentMinute < 10) {
           u8g2.print("0");
           u8g2.print(currentMinute);
         }else{
            u8g2.print(currentMinute);
            }
  /*      
       u8g2.print(currentMinute);
        u8g2.print(":");


         if (currentSecond) < 10) {
           u8g2.print("0");
           u8g2.print(currentSecond);
         }else{
            u8g2.print(currentSecond);
          }
*/
        
//        u8g2.print(currentSecond);
        u8g2.setFont(u8g2_font_courR10_tf);
      } while ( u8g2.nextPage() );
      delay(7000);


      do {
        u8g2.clearBuffer();
        u8g2.setCursor(12, 10);
        u8g2.print("Raumklima");

        u8g2.setCursor(2, 35);
        u8g2.print("Temp: ");
        u8g2.setCursor(51, 35);
        u8g2.print(temperature);
        u8g2.print("\xB0""C");

        u8g2.setCursor(2, 51);
        u8g2.print("LuFe:");
        u8g2.setCursor(51, 51);
        u8g2.print(humidity);
        u8g2.print("%");

        u8g2.setCursor(2, 63);
        u8g2.print("CO2:");
        u8g2.setCursor(51, 63);
        u8g2.print(gassensorAnalog);
        u8g2.print("ppm");

       } while ( u8g2.nextPage() );
      delay(6000);


      do {
        u8g2.clearBuffer();
        u8g2.setCursor(12, 10);
        u8g2.print("Wetterdaten");
        u8g2.setCursor(18, 22);
        u8g2.print("Tegernsee");

        u8g2.setCursor(2, 35);
        u8g2.print("Temp: ");
        u8g2.setCursor(51, 35);
        u8g2.print(maxtemp - 273.15);
        u8g2.print("\xB0""C");

        u8g2.setCursor(2, 49);
        u8g2.print("Wind:");
        u8g2.setCursor(51, 49);
        u8g2.print(myObject["wind"]["speed"]);
        u8g2.print("m/s");
        /*
              u8g2.setCursor(2, 48);
              u8g2.print("LuFe:");
              u8g2.setCursor(51, 48);
              u8g2.print(myObject["main"]["humidity"]);
              u8g2.print("%");
        */
        u8g2.setCursor(2, 63);
        u8g2.print("LuDr:");
        u8g2.setCursor(51, 63);
        u8g2.print(myObject["main"]["pressure"]);
        u8g2.print("hPa");

      } while ( u8g2.nextPage() );
      delay(1000);



      /* Cloudya:
       *   //--------- OLED Seite 1 -----------------------
      u8g2.firstPage();
      do {
        u8g2.clearBuffer();
        u8g2.setFont(u8g2_font_courB10_tf);
        u8g2.setCursor(25, 10);
        u8g2.print(weekDay);
        u8g2.setCursor(10, 27);
        u8g2.print(monthDay);
        u8g2.print(". ");
        u8g2.print(currentMonthName);
        u8g2.print(" ");
        u8g2.print(currentYear);
        u8g2.setFont(u8g2_font_courR10_tf);

        u8g2.setCursor(8, 46);
        u8g2.print("Wolken: ");
        u8g2.print(myObject["clouds"]["all"]);
        u8g2.print(" %");

        //------- IP-Adresse --------------
        u8g2.setFont(u8g2_font_courB08_tf);
        u8g2.setCursor(20, 64);
        u8g2.print(WiFi.localIP());


      } while ( u8g2.nextPage() );
      delay(8000);;

      //--------- OLED Seite 2 Wetterdaten -----------------------------
      do {
        u8g2.clearBuffer();
        u8g2.setFont(u8g2_font_courB10_tf);
        u8g2.setCursor(18, 10);
        u8g2.print("Wetterdaten");
        u8g2.setCursor(28, 22);
        u8g2.print("Tegernsee");
        u8g2.setFont(u8g2_font_courR10_tf);


        u8g2.setCursor(8, 35);
        u8g2.print("Temp: ");
        u8g2.print(maxtemp - 273.15, 1);
        u8g2.print("\xB0""C");

        u8g2.setCursor(8, 49);
        u8g2.print("Wind: ");
        //      u8g2.setCursor(51, 49);
        u8g2.print(myObject["wind"]["speed"]);
        u8g2.print("m/s");

        u8g2.setCursor(8, 63);
        u8g2.print("LuDr: ");
        //      u8g2.setCursor(51, 63);
        u8g2.print(myObject["main"]["pressure"]);
        u8g2.print("hPa");

      } while ( u8g2.nextPage() );
      delay(8000);

      //--------- OLED Seite 3 Wetterdaten -----------------------------
      do {
        u8g2.clearBuffer();
        u8g2.setFont(u8g2_font_courB10_tf);
        u8g2.setCursor(18, 10);
        u8g2.print("Wetterdaten");
        u8g2.setCursor(28, 22);
        u8g2.print("Tegernsee");
        u8g2.setFont(u8g2_font_courR10_tf);


        u8g2.setCursor(4, 36);
        u8g2.print("Feuchte: ");
        u8g2.print(myObject["main"]["humidity"]);
        u8g2.print("%");

        u8g2.setCursor(4, 50);
        u8g2.print("Wolken:  ");
        //      u8g2.setCursor(51, 49);
        u8g2.print(myObject["clouds"]["all"]);
        u8g2.print("%");

        u8g2.setCursor(4, 64);
        u8g2.print("minTemp:");
        u8g2.print(mintemp - 273.15, 1);
        u8g2.print("\xB0""C");

      } while ( u8g2.nextPage() );
      delay(8000);


      //--------- OLED Seite 4 Raumklima---------------------
      do {
        u8g2.setFont(u8g2_font_courB10_tf);
        u8g2.clearBuffer();
        u8g2.setCursor(24, 10);
        u8g2.print("Raumklima");
        u8g2.setFont(u8g2_font_courR10_tf);

        u8g2.setCursor(8, 36);
        u8g2.print("Temp: ");
        //        u8g2.setCursor(51, 30);
        u8g2.print(temperature - 1); //mit Korrektur -1°C
        u8g2.print("\xB0""C");

        u8g2.setCursor(8, 60);
        u8g2.print("LuFe: ");
        //        u8g2.setCursor(51, 44);
        u8g2.print(humidity);
        u8g2.print("%");

        u8g2.setCursor(8, 60);
        //       u8g2.print("Gas:  ");                                 // ************************** GAS SENSOR *****************************
        //        u8g2.setCursor(51, 60);
        //       u8g2.print(gassensorAnalog);
        //       u8g2.print("ppm");

      } while ( u8g2.nextPage() );
      //      delay(1000);
      //---------------------------------------------------------
    }
       */

      //---------------------------------------------------------
    }
    else {
      Serial.println("WiFi Disconnected");
    }
    lastTime = millis();
  }
}

String httpGETRequest(const char* serverName) {
  WiFiClient client;
  HTTPClient http;

  // Domain-Name
  http.begin(client, serverName);

  // HTTP POST request 200=OK
  int httpResponseCode = http.GET();

  String payload = "{}";

  if (httpResponseCode > 0) {
    Serial.print("HTTP-Antwort Code (200=OK): ");
    Serial.println(httpResponseCode);
    Serial.println("Server-Meldung: ");
    payload = http.getString();
  }
  else {
    Serial.print("Error code: ");
    Serial.println(httpResponseCode);
  }

  http.end();

  return payload;
}
